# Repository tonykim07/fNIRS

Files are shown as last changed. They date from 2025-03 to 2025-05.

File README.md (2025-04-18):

# A Wearable Functional Near-Infrared Spectroscopy (fNIRS) based Brain Interface

<div align="center">
  Device Overview
</div>

## Project Overview

This project introduces a low-cost, ergonomic functional Near-Infrared Spectroscopy (fNIRS) device designed for real-time brain activity monitoring. fNIRS is a non-invasive technique that uses near-infrared light to measure changes in blood oxygenation, providing insights into neural activity based on the modified Beer-Lambert Law.

While conventional fNIRS systems are expensive, bulky, and limited to clinical environments, this system is designed to be accessible, accurate, and user-friendly—ideal for education, personal health tracking, and portable research applications.

### System Highlights

- 24 custom sensor modules supporting 24 detectors and 8 dual-wavelength LED emitters (660 nm & 990 nm)
- Custom electrical control unit (ECU) built around a low-power STM32 microcontroller (STM32L476RET6) that interfaces with all sensor modules for synchronized control and data acquistion
- Ergonomic mechanical design for secure, comfortable wear during extended sessions
- Interactive Python-based GUI for live data visualization, serial communication, and module control

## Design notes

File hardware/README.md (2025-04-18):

# fNIRS Hardware Design

## Overview

All schematic and PCB layouts are designed with Altium Designer. The table below summarizes the hardware projects within this folder.

| Project  | Description |
|---|---|
| DetectorOptode | Sensor PCB with only photodiode detection |
| STLINK_Breakout | Breakout PCB to be able to program STM32 Microcontrollers with any STLINK/STM32 NUCLEO |
| SourceOptode | Sensor PCB with only emitters |
| fNIRS_CableAssembly | Wire harness schematics used in the final product |
| fNIRS_ECU | The electrical control unit (ECU) PCB for the entire fNIRS device |
| fNIRS_sensor_module | Sensor PCB with both detector and emitter (main sensor PCB) |

To open a project, launch the .PrjPcb file within the respective folder.

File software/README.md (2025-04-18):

# fNIRS Software Design

This software provides a graphical interface (GUI) for real-time collection, processing, and visualization of fNIRS (functional Near-Infrared Spectroscopy) data. It supports two main modes of operation:

1. **Live Readings Mode**  
   In this mode, only ADC (Analog-to-Digital Converter) data is captured and displayed on live plots. This mode is used for continuous monitoring and is ideal for observing raw signal behavior in real-time.

2. **Record & Visualize Mode**  
   In this mode, the system records data for a user-defined duration. The captured data is then taken through a series of post-processing steps (ex. interleaving sensor blocks, converting intensities to optical density, applying MBLL, and CBSI). Both ADC and mBLL (data processed by applying the Modified Beer-Lambert Law) readings are supported in this mode, and the final results are displayed on interactive graphs when processing is complete.

## Features

- **Two Operating Modes**
  - **Live Readings Mode (ADC Only):**  
    - Captures raw ADC data in real time from the serial port.
    - Displays interactive, real-time plots using PyQtGraph.
  - **Record & Visualize Mode (ADC and mBLL):**  
    - Records data for a specified duration.
    - Applies multiple post-processing steps (ex. interleaving, MBLL, CBSI).
    - Supports visualization of both raw ADC data and processed mBLL data using Plotly.

- **Data Capture and Processing**
  - Communicates with hardware over a serial port.
  - Logs raw ADC data as `all_groups.csv` in the `data/` folder.
  - Saves processed results as `processed_output.csv`.

- **Visualization Options**
  - **Interactive Static Plots (Plotly):**  
    - Supports both ADC and mBLL data.
    - Eight separate plots (one per sensor group) for displaying data recorded in `.csv` files.
    - Each plot includes its own legend and interactive mode bar (zoom, pan, full screen).
  - **Live Animations (PyQtGraph)**  
    - Supports ADC mode only.
    - Eight separate plots (one per sensor group) for displaying live readings as them come in.
  - **3D Brain Mesh**  
    - Interactive model showing brain structure, sensor positions, and group mappings.

- **Download Functionality:**
  - Export raw or processed CSV data using a simple popup prompt.

- **User-Friendly Interface:**
  - A web interface built with Bootstrap, jQuery, Plotly, and Socket.IO.
  - Control panels for sensor group selection, MUX/emitter control, and mode selection.

- **Demo Mode:**
  - A mock ADC server simulates data for testing or demonstrations.
  - Skips real data processing to simplify setup.

## Setup Instructions

1. **Clone the Repository:**
   ```bash
   git clone https://github.com/tonykim07/fNIRS.git
   cd software
   ```

2. **Set Up a Virtual Environment and Install Dependencies:**
   ```bash
   python -m venv venv
   source venv/bin/activate      # On Windows: venv\Scripts\activate
   pip install -r requirements.txt 
   ```

3. **Set COM Port (Serial Device):**

   - On Windows:
   Open PowerShell and run:
   ```bash
   Get-WMIObject Win32_SerialPort
   ```
      Look for something like COM3, COM4, etc.

   - On macOS/Linux:
   ```bash
   ls /dev/tty.*
   ```
      Look for something like /dev/tty.usbmodemXXXX or /dev/ttyUSB0.

   **Update the COM port path in config.py:**
   ```bash
   # Update this line with your actual port
   SERIAL_PORT = "COM3"       # Windows example
   # or
   SERIAL_PORT = "/dev/tty.usbmodem1234"   # macOS/Linux example
   ```
     
4. **Running the System:**

    ___Normal Mode (requires connection to serial port)___ 

    ```bash
    python visualizer.py
    ```

    ___Demo Mode___
    ```bash
    python visualizer.py demo
    ```
    Then open your browser at http://localhost:8050 to access the interface.

## Usage Overview

### Step 1: Choose Operating Mode
- **Live Readings:** for real-time, unprocessed data (ADC Only).
- **Record & Visualize:** to capture and process data for analysis (ADC and/or mBLL).

### Step 2: Start Data Capture / Recording
- Click the **Start** button to begin data acquisition.
  - In live mode, data is visualized in real time.
  - In record mode, data is recorded for a fixed duration, and logged to .csv files.

### Step 3: Stop and Visualize (mBLL Mode)
- Click **Stop and Plot** to end data capture.
- When data capsture is stopped, download options and visualization buttons for rendering static plots and animations will be displayed.

### Step 4: Analyze & Export
- **Static Plots:**  
  Click to view interactive Plotly figures with zoom, pan, and full-screen capabilities.
- **Animations:**  
  Launch real-time animation windows for dynamic analysis.
- **3D Brain Mesh:**  
  Explore the interactive 3D brain mesh with sensor nodes and sensor group highlights.
- **Download CSV Files:**  
  Click **Download CSV** to prompt for a file name and download the raw or processed data.

## File Descriptions

#### 3D Brain Model 

- **aal.nii:**  
  A NIfTI file containing anatomical brain data used to map sensor positions to brain regions.

- **BrainMesh_Ch2_smoothed.nv:**  
  Contains smoothed brain mesh data for rendering a 3D brain surface.

#### ADC Mode

- **adc_animation.py:**  
  A PyQtGraph-based script that reads ADC data from `data/all_groups.csv` and displays a full-screen real-time animation.

- **adc_client.py:**  
  A client application that uses SocketIO and PyQtGraph to receive and display live ADC data interactively.

- **adc_mock_server.py:**  
  A mock ADC server that generates fake sensor data (using, for example, a triangle wave) for demo mode.

#### mBLL Mode

- **mBLL_animation.py:**  
  A PyQtGraph script that reads processed data from `data/processed_output.csv` and displays a full-screen real-time animation of processed mBLL data.

- **mBLL_client.py:**  
  A real-time client that uses Socket.IO and PyQtGraph to display live processed (mBLL) data interactively.

- **mBLL_mock_server.py:**  
  Simulates mBLL data processing by generating dummy packets, processing them, and sending processed concentration data via Socket.IO in demo mode.

- **mBLL_server.py**  
  Reads sensor data from the serial port, processes it using MBLL and CBSI (via NIRSimple), and emits the processed concentration values via Socket.IO.

#### Others

- **fNIRS_processing.py:**  
  Processes raw ADC data by interleaving sensor blocks, converting intensities to optical density, applying MBLL and CBSI, and writes processed output to CSV files in `data/`.

- **visualizer.py:**  
  The main Flask/SocketIO server that integrates data capture, processing, interactive visualization (including static plots and animations), and control endpoints. It also supports demo mode behavior.

- **index.html**  
  The main web interface built with Bootstrap, Plotly, and jQuery. It provides a 3D brain mesh view, sensor group controls, and a mode selection panel for choosing between live ADC readings or record & visualize (ADC and/or mBLL) modes.

#### Data

- **/data Directory:**
  - **all_groups.csv**  
    CSV file that logs the raw ADC sensor data captured by the system.
  - **processed_output.csv**  
    CSV file that contains the processed fNIRS data (after applying MBLL, CBSI, etc.) used for visualization in record & visualize mode.

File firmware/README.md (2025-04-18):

# fNIRS Firmware

The firmware runs on the fNIRS ECU consisting of an STM32L476RET6 microcontroller.

## Setup

1. **Clone the Repository:**
   ```bash
   git clone https://github.com/tonykim07/fNIRS.git
   ```

2. **Open STM32CubeIDE using the `/firmware/STM32/` as the workspace directory**

3. **Clean the project, then click Build to compile the project**
   
4. **Connect an STLINK or STM32 Nucleo to the fNIRS ECU programming header (SWD Programming) and click Run to flash the board**

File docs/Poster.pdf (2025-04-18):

## Background & Motivation

## Project Goals

## Key Requirements

Final Design | Method & Results

## Conclusion & Future Work

# A Wearable Functional Near-Infrared Spectroscopy (fNIRS) based Brain Interface

### The Edward S. Rogers Sr. Department of Electrical and Computer Engineering Tony Kim, Bella Huang, Ingrid Wu, Kevin Liu

### Supervisor: Professor Xilin Liu Administrator: Professor Steve Mann

To develop a low-cost, accurate, non-invasive, and ergonomic fNIRS device that prioritizes high mobility and ease of usability, exploring the potentials of fNIRS technology beyond clinical settings.

Functional Near-Infrared Spectroscopy (fNIRS) is a non-invasive neuroimaging method which uses near-infrared light to measure blood oxygen level in the cerebral cortex, based on the modified Beer-Lambert Law (mBLL).

## ΔOD(λ) = ε(λ) ⋅ Δc ⋅ L ⋅ DPF

OD: optical density
ε : extinction coefficient
c: concentration
L: physical pathlength
DFP: differential pathlength factor

The change in optical density (ΔOD) at a given wavelength (λ) reflects how much near-infrared light is absorbed as it passes through brain tissue. Measuring ΔOD allows us to estimate changes in oxy- and deoxyhemoglobin levels, which indicate brain activity.

The fNIRS device integrates custom hardware, firmware, mechanical, and software components into a unified system. Sensors and an electrical control unit with firmware establish the foundation for signal acquisition and data transmission, while software handles analysis and graphical visualization. Finally, the mechanical components consolidate these elements into an ergonomic assembly.

The design includes 25 printed circuit boards based on two distinct cost-optimized layouts. The device supports up to 24 detector channel readings with a sampling frequency of approximately 1kHz, and 8 dual-wavelength emitters (660 nm and 940 nm) to accurately measure changes in oxyand deoxy-hemoglobin concentration levels.

Custom 4-layer PCB design
Analog multiplexing utilizing 8 TMUX1104 inline with 12-bit ADC channels
PCA9685 12-bit 16 channel
PWM controller for emitters 80MHz STM32L476RET6
microcontroller

Custom 2-layer PCB design
Photodiode detection via
transimpedance amplifier,
101 V/V post-AC gain, and
0.0796–159.2 Hz filter.
RMS noise level of ~0.004 V Emitter wavelengths of 660 nm and 940 nm

Parse and filter sensor data Apply ΔOD conversion,
mBLL, and correlation-based signal improvement (CBSI)
Graph raw ADC, ΔHbO, ΔHbR
data and display on GUI
User control for ECU to
customize operation

Conclusion
The team successfully designed and validated a low-cost, ergonomic fNIRS device and a web-based graphical user interface for real-time brain activity monitoring. The final system is able to map direct ADC output, as well as ΔHbO and ΔHbR trends that match theoretical expectations.

Sampling Rate: The device should support a minimum sampling rate of 100Hz.

Future Work
Possible future work may include real-world validation through collaboration with clinical and neuroscience researchers, as well as integrating machine learning techniques for improved noise reduction, cognitive state classification, and trend analysis of fNIRS data.

Real-time Logging: The design should be able to perform accurate real-time data processing and visualization while also keeping record of the data.

Cost: The net material and fabrication cost of the device should be below $1000.

Wearability: The assembled device can be worn, taken apart, and transported during use.

Non-invasiveness: The device should not puncture, burn, irritate the skin, or cause any form of physical harm or strain to the user.

### Project ID: 2024991

Electrical Control Unit | Sensor Modules | Software Processing

Method
Participants completed a task sequence consisting of a 20-second resting period, followed by a 20-second computer-typing task, and concluded with another 20-second resting period while wearing the device. Results
Below are two sample graphs of a single-channel recording targeting the primary motor cortex (M1).
1) Digitalized sensor data representing reflected light intensity 2) Post-processed data of the change in hemoglobin oxygenation levels using mBLL and CBSI. ADC Value

Time (s)

1) Digitalized Sensor Data

Concentration (Molar)

Time (s)

2) Post-Processed Data
Rest | Task | Rest

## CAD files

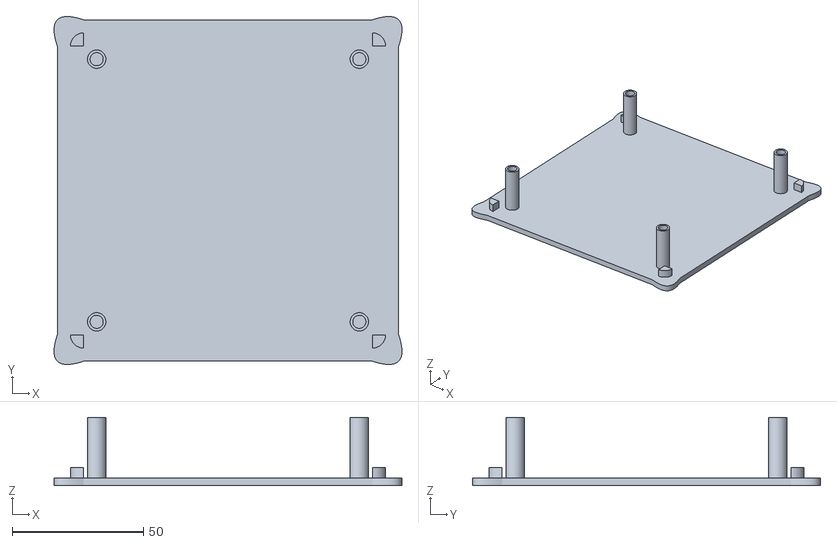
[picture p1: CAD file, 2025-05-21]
mechanical/ecu_housing_lid.stl
132.5 x 132.5 x 26.0

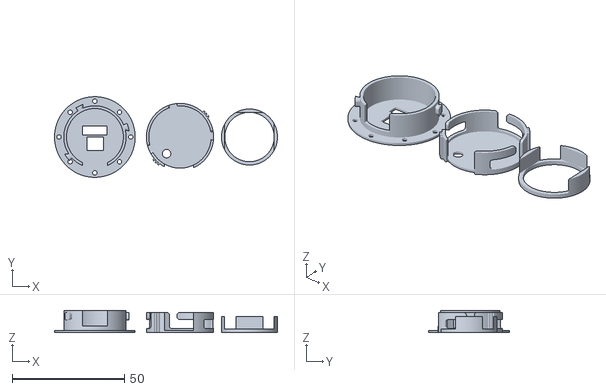
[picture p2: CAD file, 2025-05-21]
mechanical/sensor_capsule.stl
99.5 x 36.0 x 9.91

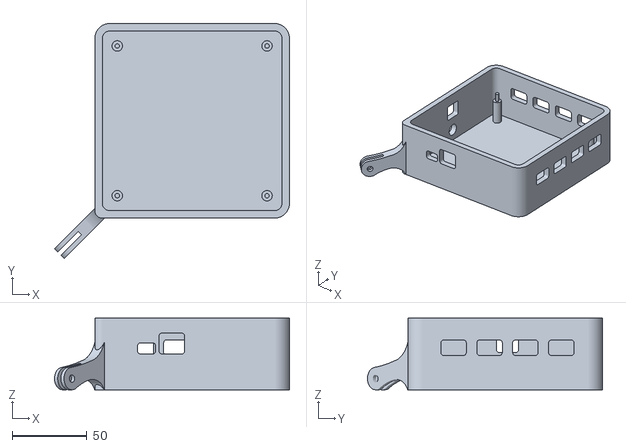
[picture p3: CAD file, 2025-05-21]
mechanical/ecu_housing_base.stl
156.9 x 156.9 x 48.0

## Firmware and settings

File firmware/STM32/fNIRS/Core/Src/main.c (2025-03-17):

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
/* Includes ------------------------------------------------------------------*/
#include "main.h"
#include "usb_device.h"

/* USER CODE BEGIN Includes */
#include "mux_control.h"
#include "emitter_control.h"
#include "sensing.h"
#include "usbd_cdc_if.h"
#include "misc.h"
#include "serial_interface.h"

/* USER CODE END Includes */

ADC_HandleTypeDef hadc1;
DMA_HandleTypeDef hdma_adc1;

I2C_HandleTypeDef hi2c1;
I2C_HandleTypeDef hi2c2;

SPI_HandleTypeDef hspi1;

TIM_HandleTypeDef htim3;
TIM_HandleTypeDef htim4;

UART_HandleTypeDef huart1;

void SystemClock_Config(void);
void PeriphCommonClock_Config(void);
static void MX_GPIO_Init(void);
static void MX_DMA_Init(void);
static void MX_ADC1_Init(void);
static void MX_I2C1_Init(void);
static void MX_I2C2_Init(void);
static void MX_SPI1_Init(void);
static void MX_USART1_UART_Init(void);
static void MX_TIM3_Init(void);
static void MX_TIM4_Init(void);
/* USER CODE BEGIN 0 */
uint8_t usb_receive_buffer[64];
/* USER CODE END 0 */

/**
  * @brief  The application entry point.
  * @retval int
  */
int main(void)
{

  /* MCU Configuration--------------------------------------------------------*/

  /* Reset of all peripherals, Initializes the Flash interface and the Systick. */
  HAL_Init();

  /* Configure the system clock */
  SystemClock_Config();

  /* Configure the peripherals common clocks */
  PeriphCommonClock_Config();

  /* Initialize all configured peripherals */
  MX_GPIO_Init();
  MX_DMA_Init();
  MX_ADC1_Init();
  MX_I2C1_Init();
  MX_I2C2_Init();
  MX_SPI1_Init();
  MX_USART1_UART_Init();
  MX_USB_DEVICE_Init();
  MX_TIM3_Init();
  MX_TIM4_Init();
  /* USER CODE BEGIN 2 */


  mux_control_init(&hi2c1);
  emitter_control_init(&hi2c2);
  sensing_init(&hadc1);

  mux_control_enable_sequencer();
  emitter_control_enable();
  emitter_control_request_operating_mode(CYCLING);

  HAL_TIM_Base_Start(&htim3);
  HAL_TIM_Base_Start_IT(&htim4);

  /* USER CODE END 2 */

  /* Infinite loop */
  /* USER CODE BEGIN WHILE */
  while (1)
  {
    /* USER CODE END WHILE */

    /* USER CODE BEGIN 3 */
    mux_control_sequencer();
    emitter_control_state_machine();
    serial_interface_rx_parse_data(usb_receive_buffer);

    if (serial_interface_rx_get_user_emitter_control_override_enable())
    {
      emitter_control_state_E override_state = serial_interface_rx_get_emitter_control_state();
      emitter_control_request_operating_mode(override_state);
    }
    else
    {
       emitter_control_request_operating_mode(CYCLING);
    }

    if (serial_interface_rx_get_user_mux_control_override_enable())
    {
      mux_control_enable_sequencer_override();
      mux_control_set_input_channel_ovr(serial_interface_rx_get_user_mux_control_state());
    }
    else
    {
      mux_control_disable_sequencer_override();
    }

    misc_toggle_led_periodic(3);
    // misc_write_to_uart_port_periodic(&huart1, "fNIRS ECU is here\n", 1);
  }

  /* USER CODE END 3 */
}

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


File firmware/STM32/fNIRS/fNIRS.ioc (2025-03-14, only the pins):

Mcu.UserName=STM32L476RETx
PA10.GPIO_Label=SPI_CS1
PA10.Signal=GPIO_Output
PA11.Signal=USB_OTG_FS_DM
PA12.Signal=USB_OTG_FS_DP
PA7.Signal=ADCx_IN12
PA8.GPIO_Label=MCU_TEST_LED
PA8.Signal=GPIO_Output
PA9.GPIO_Label=SPI_CS2
PA9.Signal=GPIO_Output
PB0.Signal=ADCx_IN15
PB13.Signal=I2C2_SCL
PB14.Signal=I2C2_SDA
PB5.Signal=SPI1_MOSI
PB6.Signal=USART1_TX
PB7.Signal=USART1_RX
PB8.Signal=I2C1_SCL
PB9.Signal=I2C1_SDA
PC0.Signal=ADCx_IN1
PC1.Signal=ADCx_IN2
PC13.GPIO_Label=SD_CARD_DETECT
PC13.Signal=GPIO_Output
PC2.Signal=ADCx_IN3
PC3.Signal=ADCx_IN4
PC4.Signal=ADCx_IN13
PC5.Signal=ADCx_IN14
PC7.GPIO_Label=PWM_CTRL_EN1
PC7.Signal=GPIO_Output

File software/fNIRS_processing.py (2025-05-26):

"""
fNIRS_processing.py
==================
This script captures raw ADC data from a serial port, processes it, and
outputs the results to a CSV file. It includes functions for parsing packets,
capturing data, interleaving mode blocks, and applying the Modified 
Beer-Lambert Law on the dataset to compute hemoglobin concentration changes.
"""

import csv
import time
import signal
import struct
import numpy as np
from tabulate import tabulate
import nirsimple.preprocessing as nsp
import nirsimple.processing as nproc
import pandas as pd
import serial
from config import SERIAL_PORT, BAUD_RATE, TIMEOUT
from scipy.signal import butter, sosfiltfilt, resample_poly, filtfilt

ser = serial.Serial(SERIAL_PORT, baudrate=BAUD_RATE, timeout=TIMEOUT)

STOP_FLAG = False  # Global flag for stopping the capture loop

def handle_stop_signal():
    """
    Signal handler for SIGUSR1 to set the STOP_FLAG.
    This allows the capture loop to stop gracefully.
    """
    global STOP_FLAG
    print("Received stop signal, setting stop_flag to True.")
    STOP_FLAG = True

# Register the handler for SIGUSR1
signal.signal(signal.SIGUSR1, handle_stop_signal)

def revert_inversion(df_in, zero_level=2050, out_csv="all_groups_no_inv.csv"):
    """
    Re-maps the Short/Long columns back to raw ADC counts and
    saves the result to `out_csv`.
    """
    df = df_in.copy()
    reading_cols = [c for c in df.columns if ("Short" in c or "Long" in c)]
    df[reading_cols] = 2 * zero_level - df[reading_cols]
    df.to_csv(out_csv, index=False)
    print(f"✓ Wrote non-inverted data → {out_csv}")
    return df

def threshold_filter(df, lower_threshold=200, upper_threshold=4000, zero_level=2050, exclude_columns=None):
    """Suppress outliers of a data frame."""
    if exclude_columns is None:
        exclude_columns = []

    suppressed_df = df.copy()

    for col in df.columns:
        if col not in exclude_columns:
            suppressed_df[col] = np.where(
                (df[col] < lower_threshold) | (df[col] > upper_threshold),
                zero_level,
                df[col]
            )

    return suppressed_df

def butter_lowpass_filter(df, cutoff_hz, fs, order=4, exclude_columns=None):
    """Apply a low-pass Butterworth filter to selected columns of a data frame."""
    if exclude_columns is None:
        exclude_columns = []

    filtered_df = df.copy()
    nyquist = 0.5 * fs
    normal_cutoff = cutoff_hz / nyquist
    b, a = butter(order, normal_cutoff, btype='low', analog=False)

    for col in df.columns:
        if col not in exclude_columns:
            filtered_df[col] = filtfilt(b, a, df[col])

    return filtered_df

def sliding_window_rms(df, emitter_col="G0_Emitter", group_prefix="G", num_groups=8,
                         remove_dc=False, split_segments_in_half=False):
    """
    Apply RMS calculation to segments defined by the 
    emitter transitions 
    """
    df_rms = df.copy()

    emitter_reference = df[emitter_col].values
    change_points = np.where(np.diff(emitter_reference) != 0)[0] + 1
    segments = np.split(np.arange(len(df)), change_points)

    if split_segments_in_half:
        split_segments = []
        for segment in segments:
            n = len(segment)
            if n == 0:
                continue
            mid = n // 2
            split_segments.append(segment[:mid])
            split_segments.append(segment[mid:])
        segments = split_segments

    groups = [f"{group_prefix}{i}" for i in range(num_groups)]

    for g in groups:
        short_col = f"{g}_Short"
        long1_col = f"{g}_Long1"
        long2_col = f"{g}_Long2"

        for segment in segments:
            if len(segment) == 0:
                continue
            segment_idx = segment.tolist()

            for col in [short_col, long1_col, long2_col]:
                segment_data = df.loc[segment_idx, col]
                if remove_dc:
                    segment_data = segment_data - segment_data.mean()
                rms_val = np.sqrt(np.mean(np.square(segment_data)))
                df_rms.loc[segment_idx, col] = rms_val

    return df_rms


def butter_bandpass_sos(lowcut, highcut, fs, order=4):
    """Return an SOS band-pass filter."""
    nyq = 0.5 * fs
    sos = butter(order, [lowcut / nyq, highcut / nyq],
                 btype="band", output="sos")
    return sos

def smart_bandpass(data, fs,
                   lowcut=0.05, highcut=0.1, order=4,
                   target_fs=20.0):
    """
    Zero-phase band-pass along *time* axis.
    `data` shape: (n_channels, n_timepoints)
    """
    # Down-sample
    if fs > target_fs + 1: # leave a little margin
        decim = int(round(fs / target_fs))
        fs_ds = fs / decim
        data_ds = resample_poly(data, up=1, down=decim, axis=1)
    else:
        decim, fs_ds, data_ds = 1, fs, data
    # Design stable filter
    sos = butter_bandpass_sos(lowcut, highcut, fs_ds, order)
    # Zero-phase filtering
    data_bp = sosfiltfilt(sos, data_ds, axis=1, padtype="odd",
                          padlen=3 * (order + 1))
    # Up-sample back if we had decimated
    if decim > 1:
        data_bp = resample_poly(data_bp, up=decim, down=1, axis=1)
    return data_bp

def parse_packet(data):
    """ 
    Parses 64 raw bytes into an 8×5 array of sensor data:
       [Group ID, Short, Long1, Long2, Emitter Status].
    """
    ZERO_LEVEL = 2050
    parsed_data = np.zeros((8, 5), dtype=int)
    for i in range(8):
        offset = i * 8
        packet_identifier = data[offset]
        sensor_channel_1 = struct.unpack('>H', data[offset+1:offset+3])[0]
        sensor_channel_inv1 = 2 * ZERO_LEVEL - sensor_channel_1
        sensor_channel_2 = struct.unpack('>H', data[offset+3:offset+5])[0]
        sensor_channel_inv2 = 2 * ZERO_LEVEL - sensor_channel_2
        sensor_channel_3 = struct.unpack('>H', data[offset+5:offset+7])[0]
        sensor_channel_inv3 = 2 * ZERO_LEVEL - sensor_channel_3
        emitter_status    = data[offset+7]

        parsed_data[i] = [
            packet_identifier,
            sensor_channel_inv1,
            sensor_channel_inv2,
            sensor_channel_inv3,
            emitter_status
        ]
    return parsed_data
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

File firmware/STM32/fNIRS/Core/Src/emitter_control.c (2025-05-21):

/* INCLUDES */
#include "emitter_control.h"
#include "pwm_driver.h"
#include "serial_interface.h"
#include "isr.h"

/* DEFINES */
// Note: lsb is read/write bit: R = 1, W = 0
#define PWM_DRIVER_SLAVE_ADDR_READ (0b10001011)
#define DEFAULT_DUTY_CYCLE (1.00)
#define DEFAULT_PHASE_SHIFT (0.00)
#define DEFAULT_PWM_FREQUENCY (1500)
#define ZERO_DUTY_CYCLE (0.00)

/* DATA STRUCTURES */

static pwm_driver_handler_S pwm_config = {
    .device_address         = PWM_DRIVER_SLAVE_ADDR_READ,
    .enable_line_gpio_pin   = PWM_CTRL_EN1_Pin,
    .gpio_port              = PWM_CTRL_EN1_GPIO_Port,
    .i2c_handler            = NULL,
    .device_config_vars     = { 0 },
    .pwm_frequency          = DEFAULT_PWM_FREQUENCY,
    .duty_cycle             = { 0 },
    .phase_shift            = { 0 },
};

static emitter_control_vars_S emitter_control_vars = { 0 };

/* FUNCTION DEFINITIONS */

static void emitter_control_update_pwm_channels(emitter_control_state_E state)
{
    switch (state)
    {
        case IDLE:
            break;

        case DISABLED:
            for (pwm_channel_E i = (pwm_channel_E)0; i < NUM_OF_PWM_CHANNELS; i++)
            {
                emitter_control_vars.duty_cycle[i] = ZERO_DUTY_CYCLE;
                emitter_control_vars.phase_shift[i] = DEFAULT_PHASE_SHIFT;
            }
            break; 

        case DEFAULT_MODE:
            // Odd numbered modules enable 940NM emitters
            // Even numbered modules enable 660NM emitters

            // Module 1
            emitter_control_vars.duty_cycle[PWM_CHANNEL0] = ZERO_DUTY_CYCLE; 
            emitter_control_vars.phase_shift[PWM_CHANNEL0] = DEFAULT_PHASE_SHIFT;
            emitter_control_vars.duty_cycle[PWM_CHANNEL1] = DEFAULT_DUTY_CYCLE;
            emitter_control_vars.phase_shift[PWM_CHANNEL1] = DEFAULT_PHASE_SHIFT;

            // Module 2
            emitter_control_vars.duty_cycle[PWM_CHANNEL2] = DEFAULT_DUTY_CYCLE; 
            emitter_control_vars.phase_shift[PWM_CHANNEL2] = DEFAULT_PHASE_SHIFT;
            emitter_control_vars.duty_cycle[PWM_CHANNEL3] = ZERO_DUTY_CYCLE;    
            emitter_control_vars.phase_shift[PWM_CHANNEL3] = DEFAULT_PHASE_SHIFT;

            // Module 3
            emitter_control_vars.duty_cycle[PWM_CHANNEL4] = ZERO_DUTY_CYCLE;
            emitter_control_vars.phase_shift[PWM_CHANNEL4] = DEFAULT_PHASE_SHIFT;
            emitter_control_vars.duty_cycle[PWM_CHANNEL5] = DEFAULT_DUTY_CYCLE;
            emitter_control_vars.phase_shift[PWM_CHANNEL5] = DEFAULT_PHASE_SHIFT;

            // Module 4
            emitter_control_vars.duty_cycle[PWM_CHANNEL6] = DEFAULT_DUTY_CYCLE;
            emitter_control_vars.phase_shift[PWM_CHANNEL6] = DEFAULT_PHASE_SHIFT;
            emitter_control_vars.duty_cycle[PWM_CHANNEL7] = ZERO_DUTY_CYCLE;
            emitter_control_vars.phase_shift[PWM_CHANNEL7] = DEFAULT_PHASE_SHIFT;
            // Module 5
            emitter_control_vars.duty_cycle[PWM_CHANNEL8] = ZERO_DUTY_CYCLE;
            emitter_control_vars.phase_shift[PWM_CHANNEL8] = DEFAULT_PHASE_SHIFT;
            emitter_control_vars.duty_cycle[PWM_CHANNEL9] = DEFAULT_DUTY_CYCLE;
            emitter_control_vars.phase_shift[PWM_CHANNEL9] = DEFAULT_PHASE_SHIFT;

            // Module 6
            emitter_control_vars.duty_cycle[PWM_CHANNEL10] = DEFAULT_DUTY_CYCLE;
            emitter_control_vars.phase_shift[PWM_CHANNEL10] = DEFAULT_PHASE_SHIFT;
            emitter_control_vars.duty_cycle[PWM_CHANNEL11] = ZERO_DUTY_CYCLE;
            emitter_control_vars.phase_shift[PWM_CHANNEL11] = DEFAULT_PHASE_SHIFT;

            // Module 7
            emitter_control_vars.duty_cycle[PWM_CHANNEL12] = ZERO_DUTY_CYCLE;
            emitter_control_vars.phase_shift[PWM_CHANNEL12] = DEFAULT_PHASE_SHIFT;
            emitter_control_vars.duty_cycle[PWM_CHANNEL13] = DEFAULT_DUTY_CYCLE;
            emitter_control_vars.phase_shift[PWM_CHANNEL13] = DEFAULT_PHASE_SHIFT;

            // Module 8
            emitter_control_vars.duty_cycle[PWM_CHANNEL14] = DEFAULT_DUTY_CYCLE;
            emitter_control_vars.phase_shift[PWM_CHANNEL14] = DEFAULT_PHASE_SHIFT;
            emitter_control_vars.duty_cycle[PWM_CHANNEL15] = ZERO_DUTY_CYCLE;
            emitter_control_vars.phase_shift[PWM_CHANNEL15] = DEFAULT_PHASE_SHIFT;

            emitter_control_vars.pwm_frequency = DEFAULT_PWM_FREQUENCY;
            break; 

        case USER_CONTROL:
            uint16_t override_data = emitter_control_vars.user_control_settings;
            for (pwm_channel_E i = (pwm_channel_E)0U; i < NUM_OF_PWM_CHANNELS; i++)
            {
                emitter_control_vars.duty_cycle[i] = (float)((override_data >> i) & 0x1);
            }
            emitter_control_vars.pwm_frequency = DEFAULT_PWM_FREQUENCY;
            break;

        case CYCLING: 
            for (pwm_channel_E i = (pwm_channel_E)0; i < NUM_OF_PWM_CHANNELS; i++)
            {
                emitter_control_vars.duty_cycle[i] = ZERO_DUTY_CYCLE; 
                emitter_control_vars.phase_shift[i] = DEFAULT_PHASE_SHIFT;
            }

            if (emitter_control_vars.timer % 2U == 0U)
            {
                for (pwm_channel_E i = (pwm_channel_E)0; i < NUM_OF_PWM_CHANNELS; i+=2)
                {
                    emitter_control_vars.duty_cycle[i] = DEFAULT_DUTY_CYCLE;
                    emitter_control_vars.phase_shift[i] = DEFAULT_PHASE_SHIFT;
                }
            }
            else
            {
                for (pwm_channel_E i = (pwm_channel_E)1; i < NUM_OF_PWM_CHANNELS; i+=2)
                {
                    emitter_control_vars.duty_cycle[i] = DEFAULT_DUTY_CYCLE;
                    emitter_control_vars.phase_shift[i] = DEFAULT_PHASE_SHIFT;
                }
            }
            break;

        case FULLY_ENABLED_940NM:
            // Even channels correspond to 940NM emitter
            for (pwm_channel_E i = (pwm_channel_E)0; i < NUM_OF_PWM_CHANNELS; i+=2)
            {
                emitter_control_vars.duty_cycle[i] = DEFAULT_DUTY_CYCLE;
                emitter_control_vars.phase_shift[i] = DEFAULT_PHASE_SHIFT;
            }

            // Make sure 660NM emitters are off
            for (pwm_channel_E i = (pwm_channel_E)1; i < NUM_OF_PWM_CHANNELS; i+=2)
            {
                emitter_control_vars.duty_cycle[i] = ZERO_DUTY_CYCLE; 
                emitter_control_vars.phase_shift[i] = DEFAULT_PHASE_SHIFT;
            }
            break;

        case FULLY_ENABLED_660NM:
            // Odd channels correspond to 660NM emitter
            for (pwm_channel_E i = (pwm_channel_E)1; i < NUM_OF_PWM_CHANNELS; i+=2)
            {
                emitter_control_vars.duty_cycle[i] = DEFAULT_DUTY_CYCLE; 
                emitter_control_vars.phase_shift[i] = DEFAULT_PHASE_SHIFT;
            }
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

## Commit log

2024-09-19 fNIRS sensor module altium project
    [fNIRS_sensor_module.PrjPcb, sensor.SchDoc]
2024-09-19 fNIRS ECU altium project setup
    [MCU.SchDoc, Power.SchDoc, SensorControl.SchDoc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]
2024-09-19 Imported sensor module components with initial schematic bring up
    [PcbLib1.PcbLib, Schlib1.SchLib, fNIRS_sensor_module.PrjPcb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]
2024-09-22 Completed sensor module schematic. PCB component layout initiated
    [PcbLib1.PcbLib, Schlib1.SchLib, SensorModule.PcbDoc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]
2024-09-27 Pushing local changes for sensor module, started ECU schematics
    [AnalogMux.SchDoc, Buffer.SchDoc, EmitterPowerControl.SchDoc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]
2024-10-08 Detector Optode PCB revision 1 completed
    [DetectorOptode.PcbDoc, DetectorOptode.PcbLib, DetectorOptode.PrjPcb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]
2024-10-08 revision 1 of detector optode PCB complete
    [SourceOptode.PrjPcb, SourceOptode.SchDoc]
2024-10-08 change of directory/file name change
    [DetectorOptode.PcbDoc, DetectorOptode.PcbLib, DetectorOptode.PrjPcb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]
2024-10-08 Source Optode PCB revision 1 complete
    [SourceOptode.PcbDoc, SourceOptode.PcbLib, SourceOptode.PrjPcb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]
2024-10-08 revision 1 PCBs
    [DetectorOptode.PcbLib, DetectorOptode.SchDoc, DetectorOptode.SchLib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]
2024-10-26 Sensing circuitry completed
    [PWM_Controller.SchDoc]
2024-10-28 generate sample sensor data and apply real-time updates on frontend
2024-10-29 fixing sd card circuitry error
    [AnalogMux.SchDoc, EmitterPowerControl.SchDoc, GPIO_Expander.SchDoc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]
2024-10-29 Sensing, PWMControl, SD card, and MCU schematics completed
    [MCU.SchDoc, OptodeControl.SchDoc, SD_Card.SchDoc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]
2024-10-31 fNIRS ECU schematic completed except for connector selection
    [AnalogMux.SchDoc, Buffer.SchDoc, Connectors.SchDoc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]
2024-10-31 fnirs ecu schematic completed except for connectors selection
2024-10-31 first revision of ecu schematic completed
    [AnalogMux.SchDoc, Buffer.SchDoc, Connectors.SchDoc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]
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2024-11-12 PCB component placement for ECU
    [AnalogMux.SchDoc, Buffer.SchDoc, Connectors.SchDoc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]
2024-11-15 passing DRC for ECU PCB
    [Connectors.SchDoc, MCU.SchDoc, OptodeConnectors.SchDoc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]
2024-11-21 completed first revision of fnirs ecu
    [GPIO_Expander.SchDoc, MCU.SchDoc, OptodeConnectors.SchDoc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]
2024-12-05 firmware with blinky and writing to uart port program, gpio expander drivers initiated
2025-01-07 hardware files up to date
    [DetectorOptode.PcbDoc, DetectorOptode.SchDoc, STLINK_Breakout.PcbDoc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]
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2025-01-10 verified i2c communication with pwm controller, updated outdated stm32 drivers
2025-01-15 initial sensing software module implementation to convert multiple adc channels and update sensor data
2025-01-17 fully functional pwm driver - tested on hardware
2025-01-17 verified ADC readings on ECU with mux control, added temporary test code for near future use
2025-02-03 sensor module PCB with emitter and detector on the same board and detector optode updated with dc offset, ac gain stage, and additional passives for hardware flexibility
    [Detector.SchDoc, DetectorOptode.PcbDoc, DetectorOptode.PrjPcb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]
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2025-02-07 emitter control default mode, fully enabled 940nm mode, fully enabled 660nm mode, and other states setup
2025-02-22 sensor module schematic updates based on hardware bringup
    [Detector.SchDoc, Emitter.SchDoc, SensorModule.PrjPcb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]
2025-02-22 sensor project update
    [SensorModule.PrjPcb]
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2025-03-12 adc sampling at 1khz with dma for multichannel select
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2025-03-12 multiplexing with dma - still some error in sampling
2025-03-12 multiplexing with dma/interrupts - still some error in output reading
    [AnalogMux.SchDoc, Buffer.SchDoc, Connectors.SchDoc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]
2025-03-12 revert emitter pwms back to original
    [emitter_control.c]
2025-03-14 revert duty cycle back to 100%
    [emitter_control.c]
2025-03-14 minor fix to transmit all sensor data
    [serial_interface.c]
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2025-03-14 added file to plot 1 sensor 1 mux
    [sensor_data.csv]
2025-03-15 removed unneeded file
    [sensor_data.csv]
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2025-03-17 merged data parser with beer lambert law in send to BL python file
    [sensor_data.csv]
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2025-03-19 update visuals for fully enabled emitter states and use different highlights for 660nm vs 940nm wavelengths
2025-03-20 cable assembly diagrams
    [PowerCable.SchDoc, SensingCables.SchDoc, SystemWiring.SchDoc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]
2025-03-21 cable assembly file and final clean up for report
    [Detector.SchDoc, SensorModule.PrjPcb, fNIRS_CableAssembly.PrjPcb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]
2025-03-21 added new file to read adc values from serial to send to GUI
2025-03-22 add legend to brain mesh and create separate UI for ADC readings
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2025-03-22 added data parser with averaging
    [sensor_data.csv]
2025-03-23 handle graceful exit on ADC client, and create mock server for ADC readings
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2025-03-24 4 second switching and moved test scripts to one folder
    [all_groups.csv]
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2025-03-25 remove csv files and added to gitignore
    [all_groups.csv, parsed_plus_inv_data.csv, sensor_data.csv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]
2025-03-25 remove csv file
    [all_groups.csv]
2025-03-25 cleaning up software folder
    [sensor_data_all_channels.csv]
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2025-03-28 add labels for live ADC readings GUI and implement new timer for fnirs_processing.py
2025-03-28 resolve timing issues with ADC post processing
    [adc_animation.py, fNIRS_processing.py, mBLL_animation.py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]
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2025-03-28 serial connection fix (not fully working)
    [adc_live.py, fNIRS_processing.py, visualizer.py]
2025-03-28 fix issue with sensor group highlights
    [visualizer.py]
2025-04-18 configure data paths for demo mode
    [all_groups.csv, interleaved_output.csv]
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2025-04-18 fix pylint errors and remove redundant code from the software directory
    [adc_animation.py, adc_client.py, adc_live.py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]
2025-05-08 fix data files path
    [visualizer.py]
2025-05-20 multiplexing improvements and small gui fixes
    [plot.py, visualizer.py]
2025-05-21 Added mechanical CAD files
    [ECU Housing Base.stl, ECU Housing Lid.stl, Sensor Capsule.stl]
2025-05-21 up to date firmware and software bug fix
    [emitter_control.c, fNIRS_processing.py, mux_control.c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]
2025-05-22 Added revert inversion logic (commented out)
    [fNIRS_processing_fix.py]
2025-05-22 Updated to include post-OD bandpass filter, channel specific length mapping, and optional ADC val inversion revert logic.
    [fNIRS_processing.py]
2025-05-26 Add CSV files with Git LFS tracking
    [interleaved_output.csv]
2025-05-26 file clean up
    [ecu_housing_base.stl, ecu_housing_lid.stl, sensor_capsule.stl]

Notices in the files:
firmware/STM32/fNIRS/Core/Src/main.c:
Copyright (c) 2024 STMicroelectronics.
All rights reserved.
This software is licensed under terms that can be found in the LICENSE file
